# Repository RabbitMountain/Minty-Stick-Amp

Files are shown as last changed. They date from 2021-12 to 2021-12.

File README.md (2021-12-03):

# Minty-Stick-Amp
DIY headphone Amplifier for the Chapman Stick

Design in Autodesk Eagle CAD, by me, Andrew Barney, December 2021. **Prototype not yet tested.**

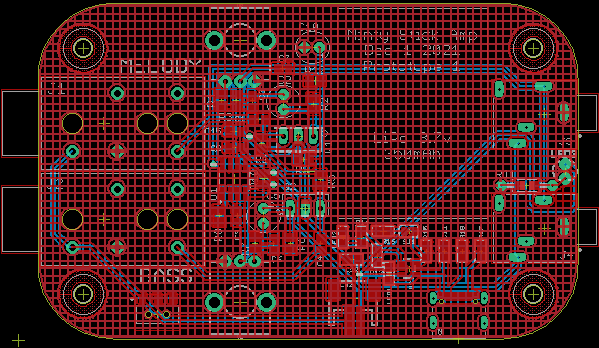
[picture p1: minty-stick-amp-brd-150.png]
Minty Stick Amp


This design is a heavily modified derivitave based on the **"Stick Amp"** by Marcelo Privé, designed and shared sometime between 2002 and 2004. Marcelo Privé's amp was an improved version of Chris Crain's original Chapman **"Stick® Player’s Headphone Amplifier"**, which was built and shared online sometime before 2003. Both designs were centered around the 1969 LM386 Low Voltage Audio Power Amplifier.

The LM386 is one of the most common amps used in DIY guitar preamplifiers due to its ability to run on a single 9V battery. The well-known "Smokey Amp" uses an LM386 and is notable for being able to fit in a cigarette package. The "Ruby" amp is a modified version of a Little Gem amplifier.

In contrast, this prototype design is designed around the more modern LM4819 and TPA321. The design should be compatible with any of the following chips that have the same basic pinout for the SOIC package. Possible IC chips include: LM4819, LM4818?, TPA751, TPA321, TPA741, TPA721, TPA711?, TPA701, TPA301. By using a more modern chip like the LM4819 or the TPA*** family means that it can run on between 2.5 VDC – 5.5 VDC. This means we can run it on a 3.7/4.2V Lipo battery instead of a large 9V battery. Low Power and small size were the main goals of this design, as well as (hopefully) being a functional christmas present for my brother Simmon.

# Schematic

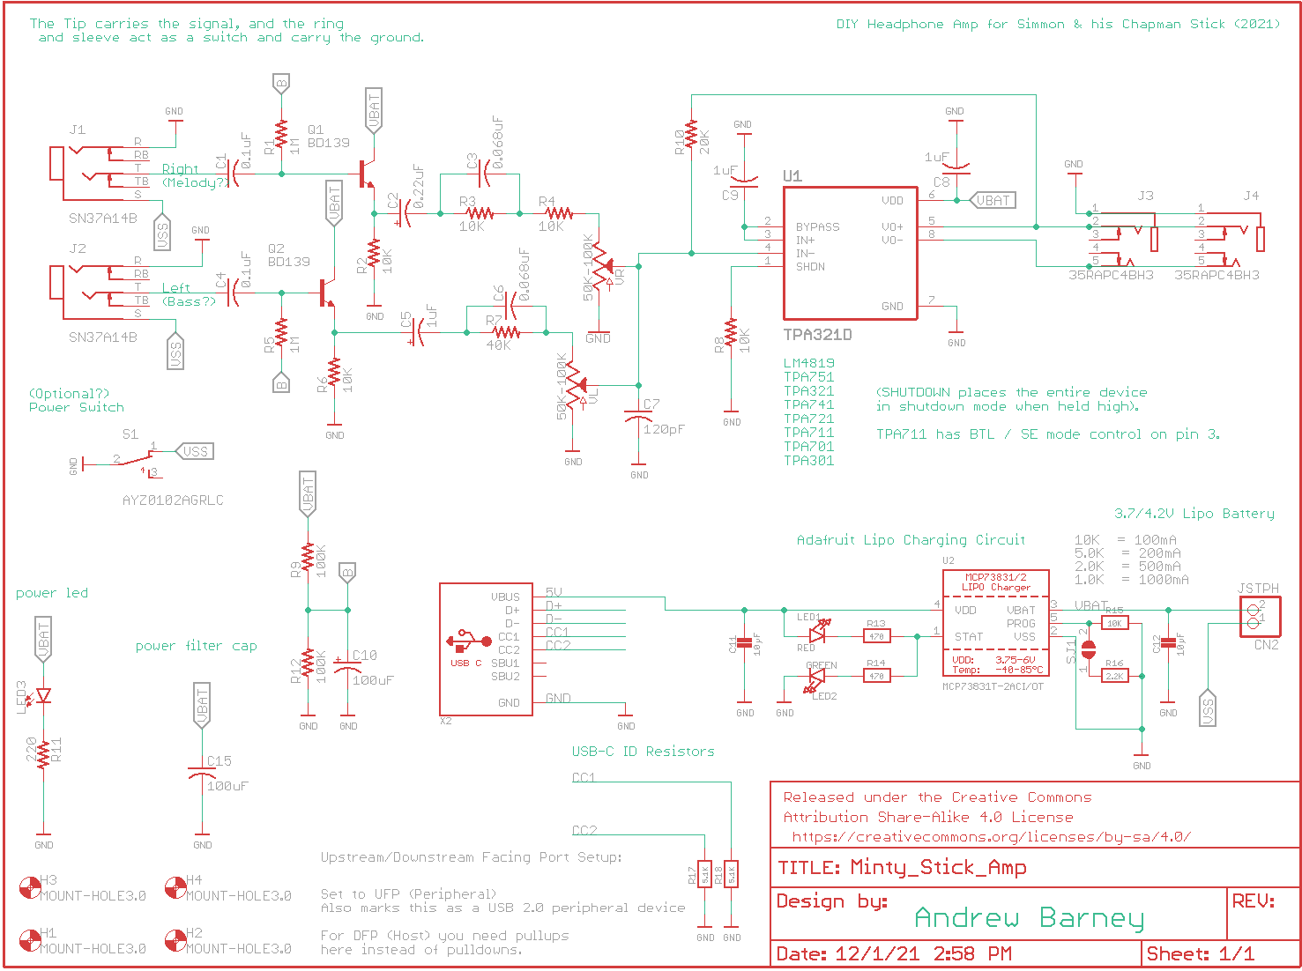
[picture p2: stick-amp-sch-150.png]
Minty Stick Amp Schematic


# Sources:

https://web.archive.org/web/20041211021643/http://home.earthlink.net/~cscrain/stick/shpamp.html

https://www.stickist.com/gallery/viewpic.php?pic_id=317

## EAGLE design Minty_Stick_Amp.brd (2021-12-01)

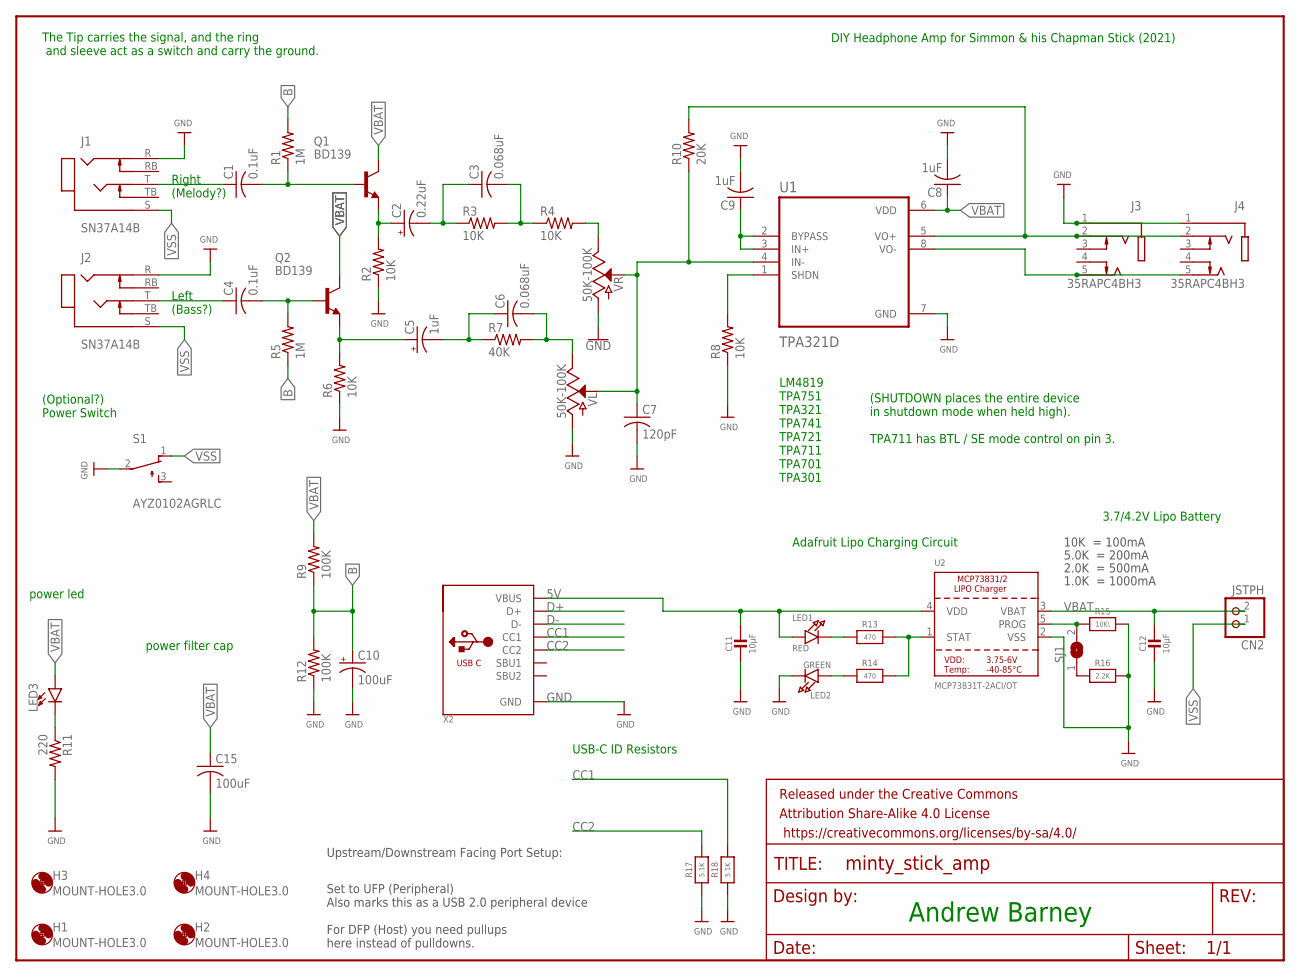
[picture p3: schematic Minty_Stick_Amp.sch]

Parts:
C1, C4: 0.1uF; C0805K
C2: 0.22uF; E2,5-6
C3, C6: 0.068uF; C0805K
C5: 1uF; E2,5-6
C7: 120pF; C0805K
C8, C9: 1uF; C0805K
C10: 100uF; E2,5-6
C11, C12: 10µF; _0805
C15: 100uF; C0805K
CN2: JSTPH; JSTPH2
FRAME1: FRAME-LETTERNO_PACKAGE; DUMMY
H1, H2, H3, H4: MOUNT-HOLE3.0; 3,0
J1, J2: SN37A14B; SWITCHCRAFT_SN37A14B
J3, J4: 35RAPC4BH3; SWITCHCRAFT_35RAPC4BH3
LED1: RED; CHIPLED_0805
LED2: GREEN; CHIPLED_0805
LED3: LED3MM; LED_3MM
Q1, Q2: BD139; TO126-V
R1, R5: 1M; M0805
R2, R3, R4, R6, R8: 10K; M0805
R7: 40K; M0805
R9, R12: 100K; M0805
R10: 20K; M0805
R11: 220; 0805-THM-7
R13, R14: 470; _0805
R15: 10K\; _0805
R16: 2.2K; _0805
R17, R18: 5.1K; _0805
S1: AYZ0102AGRLC
SJ1: SOLDERJUMPER; SOLDERJUMPER_ARROW_NOPASTE
U1: TPA321D; SOIC127P599X175-8N
U2: MCP73831T-2ACI/OT; SOT23-5
VL: 50K-100K; POT-PTH-ALPS-KIT
VR: 50K-100K; POT-PTH-ALPS-KIT
X2: USB_C; USB_C_CUSB31-CFM2AX-01-X

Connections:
5V: C11.1, LED1.A, U2.4 (VDD), X2.A4B9 (VBUS), X2.B4A9 (VBUS)
B: C10.+, R1.2, R5.1, R9.1, R12.2
CC1: R18.2, X2.A5 (CC1)
CC2: R17.2, X2.B5 (CC2)
D+: X2.A6 (D+), X2.B6 (D+)
D-: X2.A7 (D-), X2.B7 (D-)
GND: C7.2, C8.2, C9.2, C10.-, C11.2, C12.2, C15.2, J1.R, J2.R, J3.1, J4.1, LED2.C, R2.1, R6.1, R8.1, R11.2, R12.1, R15.2, R16.2, R17.1, R18.1, S1.2, U1.7 (GND), U2.2 (VSS), VL.P$3 (A), VR.P$3 (A), X2.A1B12 (GND), X2.B1A12 (GND)
unnamed: C4.1, J2.T
unnamed: R8.2, U1.1 (SHDN)
unnamed: C1.1, J1.T
unnamed: C1.2, Q1.B, R1.1
unnamed: LED3.K (C), R11.1
unnamed: C4.2, Q2.B, R5.2
unnamed: C2.+, Q1.E, R2.2
unnamed: C5.+, Q2.E, R6.2
unnamed: C2.-, C3.1, R3.1
unnamed: LED1.C, R13.1
unnamed: C3.2, R3.2, R4.1
unnamed: C5.-, C6.1, R7.1
unnamed: C6.2, R7.2, VL.P$1 (E)
unnamed: C9.1, U1.2 (BYPASS), U1.3 (IN+)
unnamed: R4.2, VR.P$1 (E)
unnamed: R13.2, R14.2, U2.1 (STAT)
unnamed: R15.1, SJ1.2, U2.5 (PROG)
unnamed: C7.1, R10.1, U1.4 (IN-), VL.P$2 (S), VR.P$2 (S)
unnamed: LED2.A, R14.1
unnamed: R16.1, SJ1.1
unnamed: J3.2, J4.2, R10.2, U1.5 (VO+)
unnamed: J3.5, J4.5, U1.8 (VO-)
VBAT: C8.1, C12.1, C15.1, CN2.2, LED3.A, Q1.C, Q2.C, R9.2, U1.6 (VDD), U2.3 (VBAT)
VSS: CN2.1, J1.S, J2.S, S1.1

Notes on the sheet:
DIY Headphone Amp for Simmon & his Chapman Stick (2021)
Left (Bass?)
Right (Melody?)
power filter cap
power led
(SHUTDOWN places the entire device in shutdown mode when held high). TPA711 has BTL / SE mode control on pin 3.
LM4819 TPA751 TPA321 TPA741 TPA721 TPA711 TPA701 TPA301
3.7/4.2V Lipo Battery
The Tip carries the signal, and the ring and sleeve act as a switch and carry the ground.
10K = 100mA
5.0K = 200mA
2.0K = 500mA
1.0K = 1000mA
Set to UFP (Peripheral) Also marks this as a USB 2.0 peripheral device For DFP (Host) you need pullups here instead of pulldowns.
Upstream/Downstream Facing Port Setup:
USB-C ID Resistors
Adafruit Lipo Charging Circuit
Andrew Barney
(Optional?) Power Switch

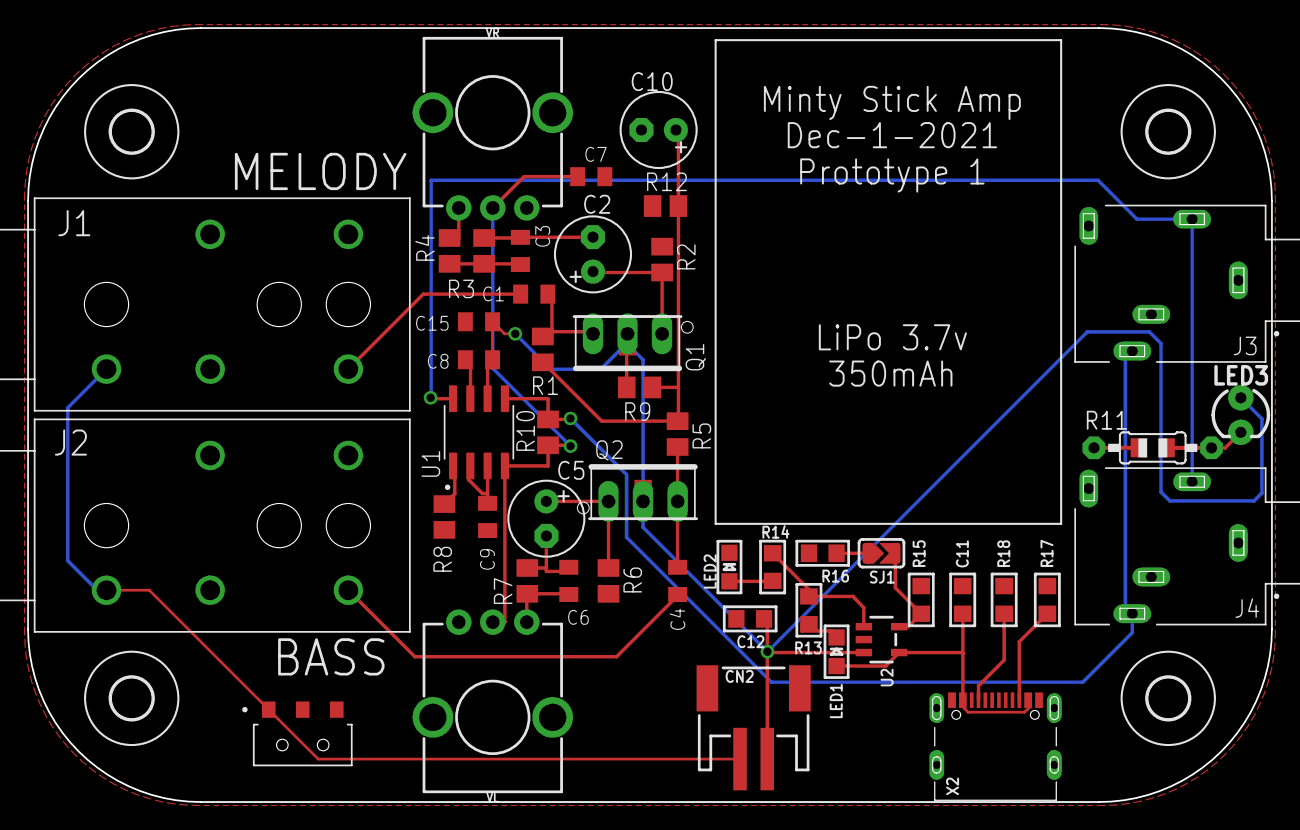
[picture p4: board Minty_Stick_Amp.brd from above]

Board: 2 copper layers, 91.4 x 56.9 mm, 54 parts (0 on the bottom side), 31 nets.

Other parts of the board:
U$2: ALTOIDSTIN-DIM

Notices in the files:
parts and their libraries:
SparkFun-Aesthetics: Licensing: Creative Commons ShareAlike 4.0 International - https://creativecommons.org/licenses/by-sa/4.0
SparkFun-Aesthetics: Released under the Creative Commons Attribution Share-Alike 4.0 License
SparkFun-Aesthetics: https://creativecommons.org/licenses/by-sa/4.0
